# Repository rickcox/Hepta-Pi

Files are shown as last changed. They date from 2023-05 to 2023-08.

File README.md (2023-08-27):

# Hepta-Pi
This is a PCB supporting a Compute Cluser of 7 Raspberrry Pi CM4 sized boards. 

- One of the boards (Board 0) has a
fairly full compliment of I/O.
- Boards 1-4, also mounted on the top, have an HDMI and a single USB
port, so can be debugged with a keyboard and monitor.
- Boards 5-6 are mounted on the bottom,
and have a bare minimum of I/O.

Only board 0 has an SD card connected, so can be a 'lite' CM4.
the other CM's must boot from on module emmc.

All 7 boards are connected to an on-board 1G ethernet switch,
which has 1 external connector.  The overall board size is 150X150mm.   The entire board is powered from a single 12V barrel jack.

I had initially conceived this as a CPU based crypto currency miner, but I later discovered that the ARM 
based CM4 boards and their competitors are not very effective crypto miners. 
So this is left as a generic compute cluster, with workload controlled by something like Kubernetes, Ansible, or Univa Grid Engine.

Here is the top view with and without CM's:
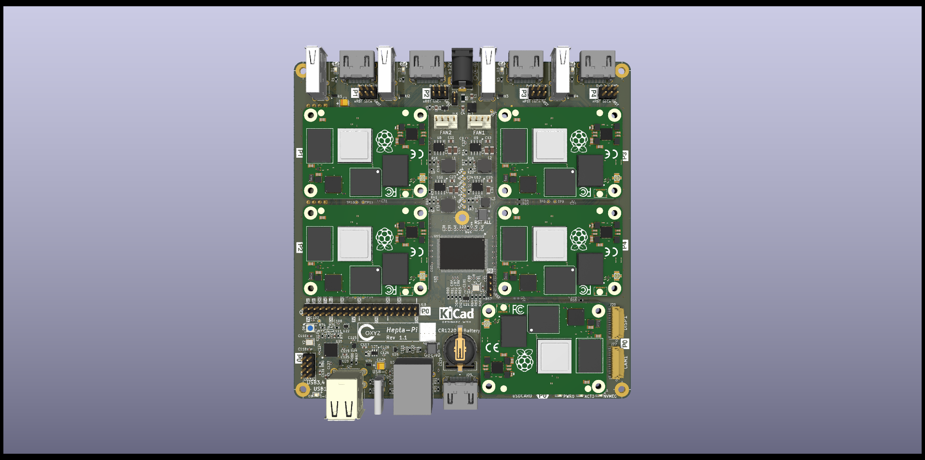
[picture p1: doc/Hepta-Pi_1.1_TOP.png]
Top View with CMs

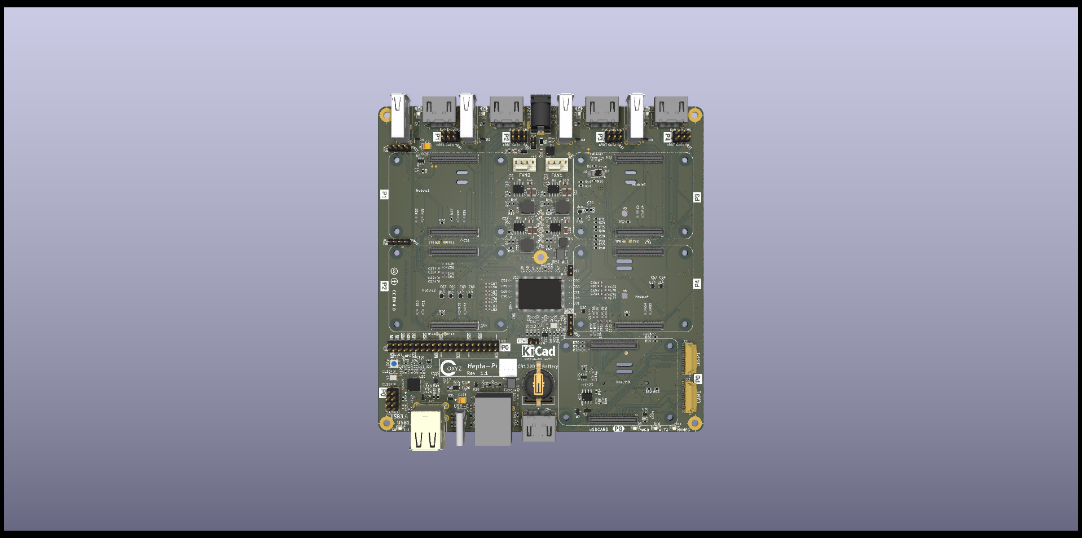
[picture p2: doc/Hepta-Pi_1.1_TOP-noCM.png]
Top View no CMs


Note that CM0 is on the top, lower right, and has the following peripherals:

- 4 USB connectors, 2 on a connector, and 2 on headers
- 1 USB-C port for EMMC burning
- 1 HDMI port
- 1 Micro SD Card
- 1 CAM and 1 DISP port for flat cables
- A PCI Port is run to a M.2 2280 or 2242 card on the bottom
- A PCF85063AT based realtime clock with CR1220 battery backup
- 2 12V PWM fan connectors that can use an EMC2301 or EMC2302 controller
- A full 40 pin Pi compatible header
- A dedicated header for an individual reset
 
CM1, 2, 3, and 4 are also on the top with the following peripherals:

- 1 USB port
- 1 HDMI port
- A dedicated header for the serial debug port and an individual reset.
  
And here is a bottom view:
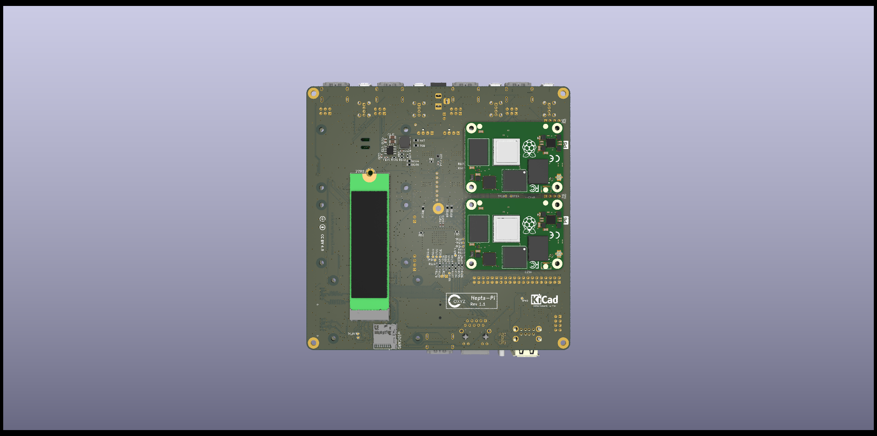
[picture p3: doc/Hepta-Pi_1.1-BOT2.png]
Bottom View with CMs

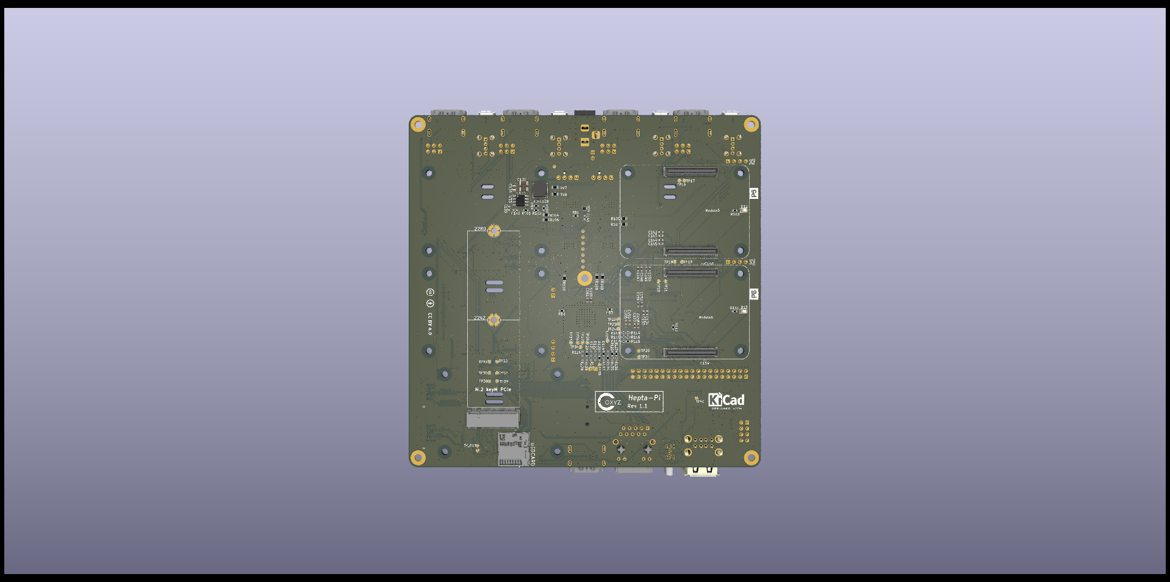
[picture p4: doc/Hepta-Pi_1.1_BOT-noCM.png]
Bottom View no CMs


CM5 and 6 have only the dedicated header for the serial debug port and an indivdual reset.

Common to everything is an RTL8370 based 1G ethernet switch, and a single ethernet port for all CM's.
There is a single 12V Barrel Connector for the board, and of course power supplies for all.

The following CM4 compatible boards have been tested:

- Raspberry Pi CM4
- Radxa ROCK3-CM
(no support for third connector)
- Pine64 Soquartz
- Banana Pi BPI-CM4

This work is licensed under a
[Creative Commons Attribution 4.0 International License][cc-by].

[][cc-by]

[cc-by]: http://creativecommons.org/licenses/by/4.0/
[cc-by-image]: https://i.creativecommons.org/l/by/4.0/88x31.png
[cc-by-shield]: https://img.shields.io/badge/License-CC%20BY%204.0-lightgrey.svg

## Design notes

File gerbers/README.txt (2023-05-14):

# export with Protel File Naming

# recommend to write all layers out from KiCad,
# then only put what the PCB manufacturer want into the zip

DESIGN='Hepta-Pi_1.1'
rm -f  ${DESIGN}.zip
zip    ${DESIGN}.zip \
	${DESIGN}*-Edge_Cuts* \
	${DESIGN}*_Cu* \
	${DESIGN}*_Mask* \
 	${DESIGN}*_Paste* \
	${DESIGN}*_Silkscreen* \
	${DESIGN}*.drl

#mv 4pi-Farm_2.51-Edge_Cuts.gm1 4pi-Farm_2.51-Edge_Cuts.gko
#mv 4pi-Farm_2.51-In1_Cu.g2 4pi-Farm_2.51-In1_Cu.g2l
#mv 4pi-Farm_2.51-In2_Cu.g3 4pi-Farm_2.51-In2_Cu.g3l
#mv 4pi-Farm_2.51.drl 4pi-Farm_2.51.xln

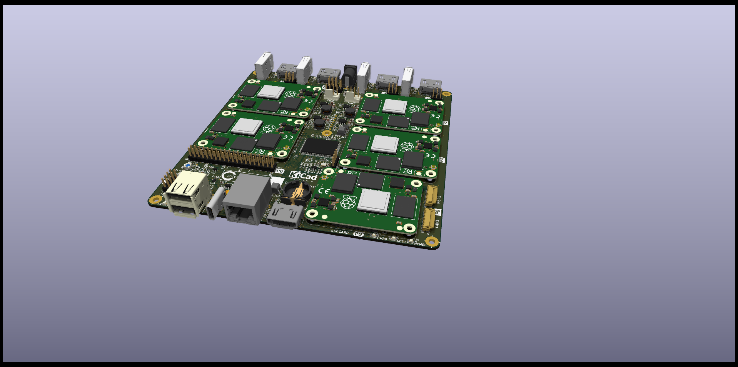
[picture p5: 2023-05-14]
doc/Hepta-Pi_1.1_FR45.png

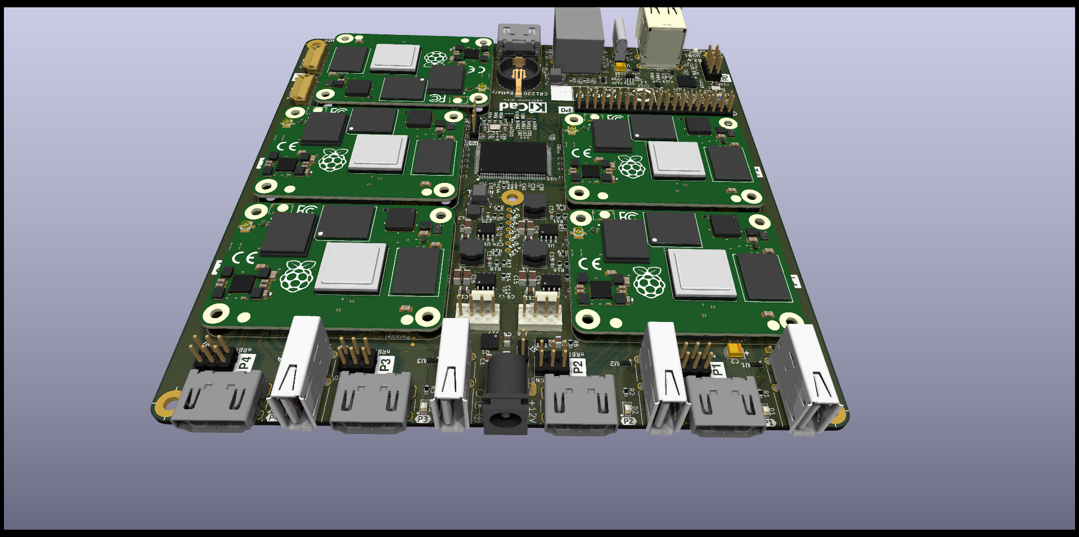
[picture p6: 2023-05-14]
doc/Hepta-Pi_1.1_BA45.png

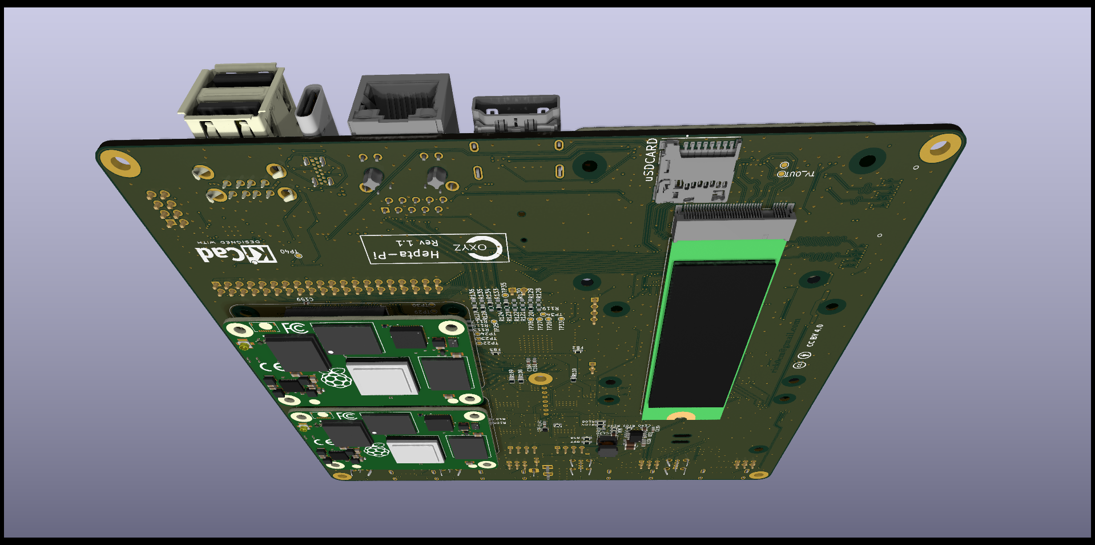
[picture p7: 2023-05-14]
doc/Hepta-Pi_1.1-BOT.png

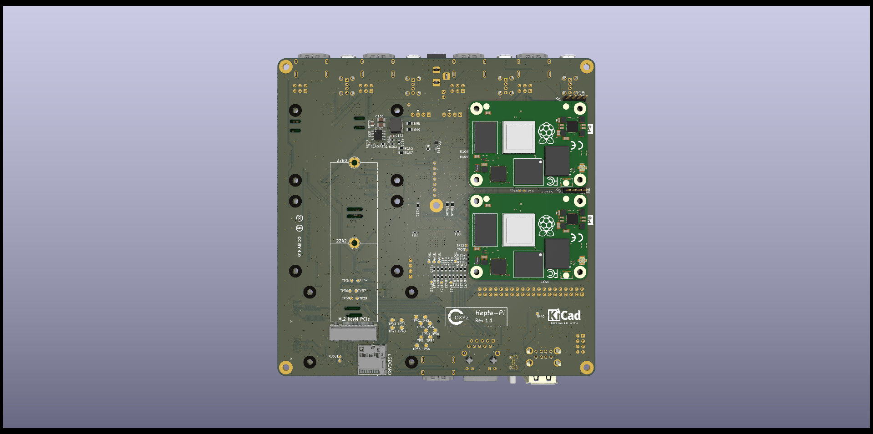
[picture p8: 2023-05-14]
doc/Hepta-Pi_1.1_BOT.png

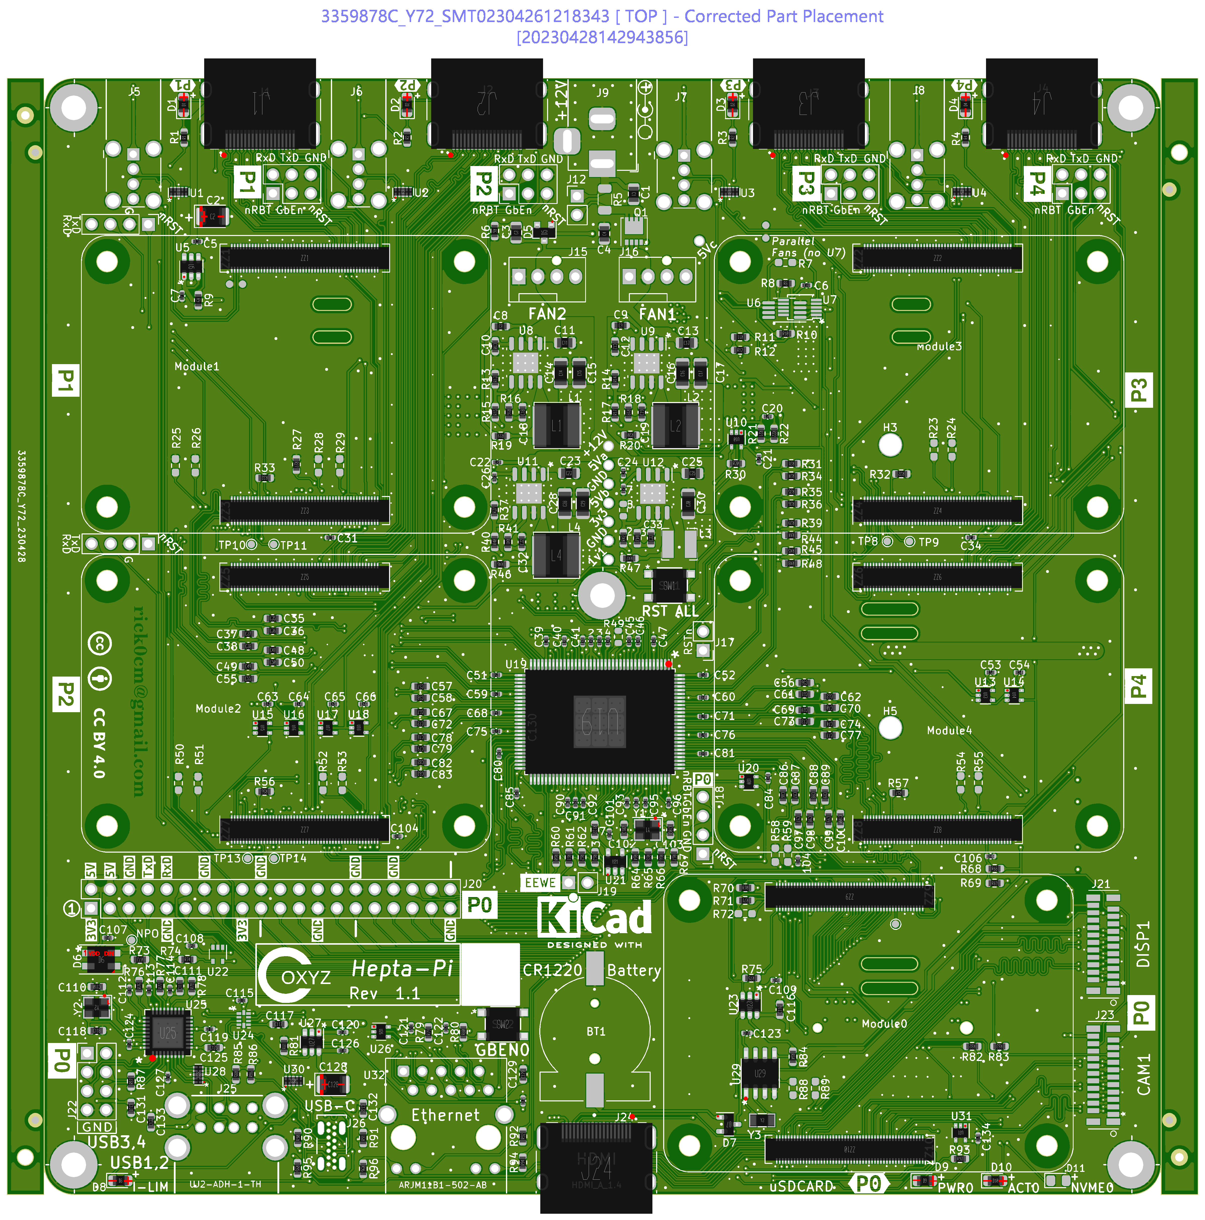
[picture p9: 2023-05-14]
doc/Produce_DanZhi.SMT_Snapshot.Top.3359878C_Y72.SMT02304261218343.png

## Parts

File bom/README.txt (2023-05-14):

BOM/CPL Procedure 30Nov2021
directory reference is boards/

IN KICAD
1) From the Schematic editor run: Schematic editor, Tools, "Generate BOM".  
     my-kicad-plugins/rick_bom/rick_bom_csv_grouped_by_value_with_fp.py
   Generates an xml netlist in the proj dir and extensive bom in proj_dir/bom.
   The bom result may be used for manual work, but is ignored in this workflow
2) From the PCB Editor run: File, Fabrication Outputs, Component Placement
   set Output:bom, Format:CSV, Units:Millimeters, File: Single file 
   This writes a generic cpl file to proj_dir/bom.
3) Now is a good time to generate gerbers and drill files to gerbers/
   And reports to doc/

AT COMMAND LINE
4) Run my-kicad-plugins/jlc-kicad-tools -v ./4pi-Farm_2.5 \
	-o ./4pi-Farm_2.5/jlcpcb | tee jlcpcb/jlc-kicad-tools.log
   ( pip install git+https://github.com/matthewlai/JLCKicadTools )

   This:
   - Reads the xml netlist to access all of the component info
   - Reads the cpl files to get component locations, orientation, and side
     (rotation exceptions@ ~/.local/lib/python*/site_packages/jlc-kicad-tools/)
   - Writes bom_jlc and cpl_jlc files to the jlcpcb/ directory
5) Manual post-edits:
   - Strip off the back side components from cpl - No support for 2-sided assy
   - Things to review/edit in the BOM/CPL:
     o Add in the Pi4CM 100 pin connectors to bom
     o Create a mini-bom for jlcpcb assembly with stuff removed:
     o Delete any through hole components from mini-bom
       unless you want to pay for hand assy
     o Delete any components from mini-bom you want to hand assemble later
     o LCSC Part numbers in BOM - Check - are they current and available, 
       and Basic rather than Extended parts if possible?
       You get a chance to edit this again once entered into jlcpcb's system
6) zip up the gerber files prior to submitting

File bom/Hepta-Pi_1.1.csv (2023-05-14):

Source: | /mnt/sebastian-rick/boards/Hepta-Pi_1.1/Hepta-Pi_1.1.kicad_sch
Date: | Sun 23 Apr 2023 07:32:42 PM PDT
Tool: | Eeschema 7.0.2-6a45011f42~172~ubuntu22.04.1
Generator: | /home/rick/boards/my-kicad-plugins/rick_bom/rick_bom_csv_grouped_by_value_with_fp.py
Component Count: | 414
Ref | Qnty | Value | Cmp name | Footprint | Description | Manufacturer | Manuf Partno | LCSC Part Number | Special
BT1, | 1 | S8411-45R | S8411-45R | CM4IO:BAT_S8411-45R |  |  |  | C238068
C1, C3, | 2 | 100n 100v | C | Capacitor_SMD:C_0805_2012Metric | Unpolarized capacitor |  |  | C28233
C2, C128, | 2 | 100u | C_Polarized | Capacitor_Tantalum_SMD:CP_EIA-3528-21_Kemet-B | Polarized capacitor |  |  | C16133
C4, C11, C13, C23, C25, C136, | 6 | 10u 25v | C | Capacitor_SMD:C_0805_2012Metric | Unpolarized capacitor |  |  | C440198
C5, C6, C7, C20, C21, C22, C24, C26, C27, C31, C34, C39, C40, C41, C42, C43, C44, C45, C46, C47, C51, C52, C53, C54, C59, C60, C63, C64, C65, C66, C68, C71, C75, C76, C80, C81, C84, C85, C90, C91, C92, C93, C94, C95, C96, C101, C104, C105, C106, C107, C108, C109, C112, C113, C114, C115, C119, C120, C121, C122, C123, C124, C126, C127, C130, C134, C146, C159, | 68 | 100n | C | Capacitor_SMD:C_0402_1005Metric | Unpolarized capacitor |  |  | C1525
C8, C9, C10, C12, C35, C36, C37, C38, C48, C49, C50, C55, C56, C57, C58, C61, C62, C67, C69, C70, C72, C73, C74, C77, C78, C79, C82, C83, C86, C87, C88, C89, C97, C98, C99, C100, C129, C139, C140, C141, C142, C143, C144, C145, C147, C148, C149, C150, C151, C152, C153, C154, C155, C156, C157, C158, C160, C161, | 58 | 100n | C | Capacitor_SMD:C_0603_1608Metric | Unpolarized capacitor |  |  | C14663
C14, C15, C16, C17, C28, C29, C30, C135, C137, | 9 | 47u | C | Capacitor_SMD:C_1206_3216Metric | Unpolarized capacitor |  |  | C96123
C18, C19, C32, C33, C138, | 5 | 3.0n | C | Capacitor_SMD:C_0603_1608Metric | Unpolarized capacitor |  |  | C1613
C102, C103, | 2 | 12p | C | Capacitor_SMD:C_0603_1608Metric | Unpolarized capacitor |  |  | C38523
C110, C118, | 2 | 20p | C | Capacitor_SMD:C_0603_1608Metric | Unpolarized capacitor |  |  | C1648
C111, C116, C125, C131, C132, C133, | 6 | 10u | C | Capacitor_SMD:C_0603_1608Metric | Unpolarized capacitor |  |  | C19702
C117, | 1 | 1u | C | Capacitor_SMD:C_0603_1608Metric | Unpolarized capacitor |  |  | C15849
D1, D2, D3, D4, D10, D12, D13, | 7 | LED_GREEN | LED_Small | LED_SMD:LED_0805_2012Metric_Pad1.15x1.40mm_HandSolder | Light emitting diode, small symbol |  |  | C2297
D5, | 1 | MMBZ5242BLT3G | BZX84Cxx | CM4IO:D_SOT-23_ANK | 300mW Zener Diode, SOT-23 |  |  | C112551
D6, | 1 | WS8212B-MINI | WS2812B | LED_SMD:LED_SK6812MINI_PLCC4_3.5x3.5mm_P1.75mm | RGB LED with integrated controller |  |  | C527089
D7, | 1 | BAT54C-7-F | BAT54C | Package_TO_SOT_SMD:SOT-23 | dual schottky barrier diode, common cathode |  |  | C181200
D8, | 1 | LED_YELLOW | LED | LED_SMD:LED_0805_2012Metric_Pad1.15x1.40mm_HandSolder | Light emitting diode |  |  | C2296
D9, | 1 | LED_RED | LED | LED_SMD:LED_0805_2012Metric_Pad1.15x1.40mm_HandSolder | Light emitting diode |  |  | C84256
D11, | 1 | LED_BLUE | LED | LED_SMD:LED_0805_2012Metric_Pad1.15x1.40mm_HandSolder | Light emitting diode |  |  | C99870
FB1, FB2, FB3, | 3 | FerriteBead_Small | FerriteBead_Small | Resistor_SMD:R_0603_1608Metric | Ferrite bead, small symbol |  |  | C108301
H1, H2, H4, H6, H7, | 5 | MountingHole_Pad | MountingHole_Pad | MountingHole:MountingHole_3.2mm_M3_Pad_TopBottom | Mounting Hole with connection |  |  | DNP
H3, | 1 | M.2 2280 Mount | MountingHole_Pad | CM4IO:M.2_Standoff | Mounting Hole with connection |  | SM3ZS067U310-NUT1
H5, | 1 | M.2 2242 Mount | MountingHole_Pad | CM4IO:M.2_Standoff | Mounting Hole with connection |  | SM3ZS067U310-NUT1
J1, J2, J3, J4, J24, | 5 | HDMI_A_1.4 | HDMI_A_1.4 | CM4IO:EDAC 690-019-298-412 | HDMI 1.4+ type A connector |  |  | C720616
J5, J6, J7, J8, | 4 | USB_A | USB_A | Connector_USB:USB_A_Wuerth_614004134726_Horizontal | USB Type A connector |  |  | C305979
J9, | 1 | Barrel_Jack | Barrel_Jack | Connector_BarrelJack:BarrelJack_Horizontal |  |  |  |  | TH
J10, J11, J13, J14, | 4 | Conn_02x03_Odd_Even | Conn_02x03_Odd_Even | Connector_PinHeader_2.54mm:PinHeader_2x03_P2.54mm_Vertical | Generic connector, double row, 02x03, odd/even pin numbering scheme (row 1 odd numbers, row 2 even numbers), script generated (kicad-library-utils/schlib/autogen/connector/) |  |  |  | TH
J12, | 1 | Conn_01x02 | Conn_01x02 | Connector_PinHeader_2.54mm:PinHeader_1x02_P2.54mm_Vertical | Generic connector, single row, 01x02, script generated (kicad-library-utils/schlib/autogen/connector/) |  |  |  | TH
J15, J16, | 2 | Molex 470531000 | Conn_01x04 | Connector:FanPinHeader_1x04_P2.54mm_Vertical | Generic connector, single row, 01x04, script generated (kicad-library-utils/schlib/autogen/connector/) |  |  |  | TH
J17, | 1 | RSTn | Conn_01x02 | Connector_PinHeader_2.54mm:PinHeader_1x02_P2.54mm_Vertical | Generic connector, single row, 01x02, script generated (kicad-library-utils/schlib/autogen/connector/)
J18, | 1 | Conn_01x04 | Conn_01x04 | Connector_PinHeader_2.54mm:PinHeader_1x04_P2.54mm_Vertical | Generic connector, single row, 01x04, script generated (kicad-library-utils/schlib/autogen/connector/) |  |  |  | TH
J19, | 1 | EEWE | Conn_01x02 | Connector_PinHeader_2.54mm:PinHeader_1x02_P2.54mm_Vertical | Generic connector, single row, 01x02, script generated (kicad-library-utils/schlib/autogen/connector/)
J20, | 1 | THD-20-R | Conn_02x20_Odd_Even | Connector_PinHeader_2.54mm:PinHeader_2x20_P2.54mm_Vertical | Generic connector, double row, 02x20, odd/even pin numbering scheme (row 1 odd numbers, row 2 even numbers), script generated (kicad-library-utils/schlib/autogen/connector/)
J21, J23, | 2 | Conn_01x22_Female | Conn_01x22_Female | CM4IO:Hirose_FH12-22S-0.5SV55_P0.5mm_Vertical | Generic connector, single row, 01x22, script generated (kicad-library-utils/schlib/autogen/connector/) |  | FH12-22S-0.5SV(55)
J22, | 1 | Conn_02x04_Odd_Even | Conn_02x04_Odd_Even | Connector_PinHeader_2.54mm:PinHeader_2x04_P2.54mm_Vertical | Generic connector, double row, 02x04, odd/even pin numbering scheme (row 1 odd numbers, row 2 even numbers), script generated (kicad-library-utils/schlib/autogen/connector/) |  |  | C124386
J25, | 1 | UJ2-ADH-1-TH | USB_67298-4090 | CM4IO:MOLEX_USB_67298-4090 |  | Molex | None | C12049 | Farnell
J26, | 1 | 216989-0001 | 216989-0001 | CM4IO:Molex-216989-0001-MFG | 216989-0001 |  | 216989-0001
J27, J28, | 2 | Conn_01X04 | Conn_01x04 | Connector_PinHeader_2.54mm:PinHeader_1x04_P2.54mm_Vertical | Generic connector, single row, 01x04, script generated (kicad-library-utils/schlib/autogen/connector/) |  |  |  | TH
J29, | 1 | SM3ZS067U310AMR1200 | SM3ZS067U310AMR1200 | CM4IO:JAE_SM3ZS067U310AMR1200 | Connector M.2 PCIe, 0.5mm pitch, M Key |  | SM3ZS067U310AMR1200 | C4527433
J30, | 1 | Micro_SD_Card_Det | Micro_SD_Card_Det | CM4IO:SDCARD_MOLEX_503398-1892 | Micro SD Card Socket with card detection pins |  |  | C428492
L1, L2, L4, L5, | 4 | 6045-3R3 | INDUCTOR | Inductor_SMD:L_Bourns_SRN6045TA | Inductor symbol for simulation only |  |  | C135301
L3, | 1 | 4018-3R3 | INDUCTOR | Inductor_SMD:L_Bourns-SRN4018 | Inductor symbol for simulation only |  |  | C307830
Module0, Module1, Module2, Module3, Module4, Module5, Module6, | 7 | ComputeModule4-CM4 | ComputeModule4-CM4 | CM4IO:Raspberry-Pi-4-Compute-Module |  |  |  |  | Hirose
NT1, NT2, | 2 | NetTie_2 | NetTie_2 | NetTie:NetTie-2_SMD_Pad0.5mm | Net tie, 2 pins |  |  | DNP | DNP
Q1, | 1 | DMP3013SFV-7 | DMP3013SFV | Package_SON:Diodes_PowerDI3333-8 | -12A Id, -30V Vds, P-Channel Power MOSFET, 9.5mOhm Ron, 33.7nC Qg (typ), PowerDI3333-8 |  |  | C264098
R1, R2, R3, R4, R27, R32, R33, R56, R57, R82, R83, R93, R96, R103, R111, R112, R137, | 17 | 1K | R | Resistor_SMD:R_0603_1608Metric | Resistor |  |  | C21190
R5, | 1 | 0R002 | R_Small_US | Resistor_SMD:R_1206_3216Metric | Resistor, small US symbol |  |  | C154630
R6, R75, R87, | 3 | 12.1K 1% | R | Resistor_SMD:R_0603_1608Metric | Resistor |  |  | C22864
R7, R88, R89, | 3 | DNP | R | Resistor_SMD:R_0603_1608Metric_Pad0.98x0.95mm_HandSolder | Resistor |  |  | DNP | DNP
R8, R9, R10, R73, R76, R77, R78, R84, | 8 | 36K 1% | R | Resistor_SMD:R_0603_1608Metric | Resistor |  |  | C23147
R11, R12, R31, R34, R35, R36, R39, R44, R45, R48, R60, R61, R62, R63, R66, R67, R71, | 17 | 0R | R | Resistor_SMD:R_0603_1608Metric | Resistor |  |  | C21189
R13, R14, R37, R70, R81, R101, | 6 | 22.1K 1% | R | Resistor_SMD:R_0603_1608Metric | Resistor |  |  | C25961
R15, R17, R102, | 3 | 118K 1% | R | Resistor_SMD:R_0603_1608Metric | Resistor |  |  | C25806
R16, R18, R41, R42, R99, | 5 | 11.0K 1% | R | Resistor_SMD:R_0603_1608Metric | Resistor |  |  | C25950
R19, R20, R46, R47, R74, R100, | 6 | 5R | R | Resistor_SMD:R_0603_1608Metric | Resistor |  |  | C25197
R21, R22, R79, R80, R95, | 5 | 510K 1% | R | Resistor_SMD:R_0603_1608Metric | Resistor |  |  | C23192
R23, R24, R25, R26, R28, R29, R50, R51, R52, R53, R54, R55, R58, R59, | 14 | 180R DNP | R | Resistor_SMD:R_0603_1608Metric_Pad0.98x0.95mm_HandSolder | Resistor |  |  | DNP | DNP
R30, | 1 | 18K 1% | R | Resistor_SMD:R_0603_1608Metric | Resistor |  |  | C25810
R38, | 1 | 13.8K 1% | R | Resistor_SMD:R_0603_1608Metric | Resistor |  |  | C862888
R40, | 1 | 69.8K 1% | R | Resistor_SMD:R_0603_1608Metric | Resistor |  |  | C23098
R43, | 1 | 3.32K 1% | R | Resistor_SMD:R_0603_1608Metric | Resistor |  |  | C22995
R49, | 1 | 2.49K 1% | R | Resistor_SMD:R_0603_1608Metric | Resistor |  |  | C227773
R64, R65, R68, R69, | 4 | 4K7 | R | Resistor_SMD:R_0603_1608Metric | Resistor |  |  | C99782
R72, | 1 | 0R DNP | R | Resistor_SMD:R_0603_1608Metric_Pad0.98x0.95mm_HandSolder | Resistor |  |  | C21189 | DNP
R85, R86, | 2 | 2.2K 1% | R | Resistor_SMD:R_0603_1608Metric | Resistor |  |  | C4190
R90, R91, | 2 | 5.1K | R | Resistor_SMD:R_0603_1608Metric | Resistor |  |  | C23186
R92, R94, | 2 | 470R | R | Resistor_SMD:R_0603_1608Metric | Resistor |  |  | C23179
R97, R98, R104, R105, R106, R107, R108, R109, R110, | 9 | 0R HC | R | Resistor_SMD:R_0805_2012Metric_Pad1.20x1.40mm_HandSolder | Resistor |  |  | C1882631
R113, R114, R115, R116, R117, R119, R121, R122, R123, R125, R128, R129, R130, R131, R133, R135, R136, | 17 | 4K7 DNP | R | Resistor_SMD:R_0603_1608Metric_Pad0.98x0.95mm_HandSolder | Resistor |  |  | C99782 | DNP
R118, | 1 | 4K7 | R | Resistor_SMD:R_0603_1608Metric_Pad0.98x0.95mm_HandSolder | Resistor |  |  | C99782 | DNP
R120, R124, R126, R127, R132, R134, | 6 | 4K7 | R | Resistor_SMD:R_0603_1608Metric_Pad0.98x0.95mm_HandSolder | Resistor |  |  | C99782 | DNP
SW1, SW2, | 2 | pushButton-PTS647SM38SMTR2LFS | pushButton-PTS647SM38SMTR2LFS | CM4IO:pushButton-PTS647SM38SMTR2LFS |  |  |  | C2689502
U1, U2, U3, U4, U28, U30, | 6 | TPD4EUSB30 | TPD4EUSB30 | Package_SON:USON-10_2.5x1.0mm_P0.5mm | 4-Channel ESD Protection for Super-Speed USB 3.0 Interface, USON-10 |  |  | C558427
U5, U23, U27, | 3 | AP22653W6-7 | AP2553W6_1 | Package_TO_SOT_SMD:SOT-23-6 |  |  |  | C2158037
U6, | 1 | EMC2301 nDNP | EMC2301 | Package_SO:MSOP-8_3x3mm_P0.65mm |  |  |  | DNP | DNP
U7, | 1 | EMC2302-2-AIZL-TR | EMC2302 | Package_SO:MSOP-10_3x3mm_P0.5mm | Dual RPM-Based PWM Fan Controller |  |  | C626970
U8, U9, U11, U33, | 4 | AP64501SP-13 | AP64351 | Package_SO:SOIC-8-1EP_3.9x4.9mm_P1.27mm_EP2.95x4.9mm_Mask2.71x3.4mm |  |  |  | C2071517
U10, U13, U14, U15, U16, U17, U18, U20, U26, U31, | 10 | 74LVC1G07SE-7 | 74LVC1G07_copy | Package_TO_SOT_SMD:SOT-353_SC-70-5 | Single Buffer Gate w/ Open Drain, Low-Voltage CMOS |  |  | C67531
U12, | 1 | AP64351SP-13 | AP64351 | Package_SO:SOIC-8-1EP_3.9x4.9mm_P1.27mm_EP2.95x4.9mm_Mask2.71x3.4mm
U19, | 1 | RTL8370N | RTL8370N | CM4IO:LQFP-128_14x20mm_P0.5mm |  |  |  | C2803243
U21, | 1 | 24C04-I2C-EEPROM | 24AA02-OT | Package_TO_SOT_SMD:SOT-23-5 | I2C Serial EEPROM, 2Kb, SOT-23 |  |  | C123842
U22, | 1 | 74AHCT1G126SE-7 | 74AHCT1G126 | Package_TO_SOT_SMD:SOT-353_SC-70-5 | Single Buffer Gate Tri-State, Low-Voltage CMOS |  |  | C150723
U24, | 1 | PI3USB4000D | PI3USB4000D | Package_DFN_QFN:Texas_R-PUQFN-N10 | USB2 1:2 Mux/DeMux |  |  | C3656785
U25, | 1 | USB2514B-I/M2 | USB2514B_Bi | Package_DFN_QFN:QFN-36-1EP_6x6mm_P0.5mm_EP3.7x3.7mm | USB 2.0 Hi-Speed Hub Controller |  |  | C16251
U29, | 1 | PCF85063AT/AAZ | PCF8563T | Package_SO:SOIC-8_3.9x4.9mm_P1.27mm | Realtime Clock/Calendar I2C Interface, SOIC-8 |  |  | C2157792
U32, | 1 | Abracon_ARJM11B1-502-AB | Abracon_ARJM11B1-502-AB | CM4IO:ARJM11B1-502-AB | RJ45 Ethernet Jack w/ Magnetics, 10/100/1G, Tab down, No EMI Fingers, G+Y LEDs |  |  | C240190
U34, | 1 | TMP102xxDRL | TMP102xxDRL | Package_TO_SOT_SMD:SOT-563 | Digital Temperature Sensor, +/- 3 °C, low-Power, SMBus, 12 bit, Two-Wire Serial Interface, SOT-563
Y1, | 1 | 25MHZ | Crystal_GND24 | Crystal:Crystal_SMD_3225-4Pin_3.2x2.5mm | Four pin crystal, GND on pins 2 and 4 |  |  | C9006
Y2, | 1 | 24MHZ | Crystal_GND24 | Crystal:Crystal_SMD_3225-4Pin_3.2x2.5mm | Four pin crystal, GND on pins 2 and 4 |  |  | C70571
Y3, | 1 | X32K768S301 | Crystal_Small | Crystal:Crystal_SMD_3215-2Pin_3.2x1.5mm | Two pin crystal, small symbol |  |  | C32346

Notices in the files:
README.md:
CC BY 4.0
